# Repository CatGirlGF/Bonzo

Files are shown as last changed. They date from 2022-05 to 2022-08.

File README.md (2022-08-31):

# Bonzo
## Pro Micro based custom pseudo 40% keyboard inspired by [V4N4G0N](https://trashman.wiki/keyboards/v4n4g0n)

Bonzo

## Kicad libraries used:

https://github.com/AcheronProject/AlexandriaLibrary
https://github.com/keebio/Keebio-Parts.pretty
https://github.com/ai03-2725/MX_Alps_Hybrid/tree/master/MX_Only.pretty

## Gerbers

The provided gerbers have been created according to the specifications of JLCpcb. For plate the size is 275.3mm * 113.4mm

## Cases 

### Acryllic case

The case is designed to be cut out of 3mm acryllic and uses a 1.5mm switchplate.

I used 4mm female to female M2 standoffs from this listing: https://www.aliexpress.com/item/1005003106030065.html

https://i.imgur.com/W8KVRhH.png Picture for reference if the listing gets deleted

### 3D printable case WIP

This case has been printed fully and works, but the screwholes are too tight and have to be drilled.

Updated case design with heat insrets and correct size holes at some point.

## Firmware 

I have provided a compiled .hex and a layout json that will let you use the keyboard with VIA.

The full QMK library is also provided incase it is needed.

## BOM

### General parts for wired

| Name | Pieces | Description |
| --- | --- | --- |
| PCB | 1 | Gerbers available at this repository |
| 1,5mm switch plate | 1 | Gerbers available at this repository |
| 2U PCB mount stabilizer | 3 | Also known as screw-in stabilizers |
| MX hotswap sockets | 54 | Kailh or equivalent |
| MX style switch | 54 | |
| 1N4148 diodes | 54 | SOD-123 packaging |
| ProMicro or similar | 1 | |

### For Wireless

| Name | Pieces | Description |
| --- | --- | --- |
| PCB | 1 | Gerbers available at this repository |
| 1,5mm switch plate | 1 | Gerbers available at this repository |
| 2U PCB mount stabilizer | 3 | |
| MX hotswap sockets | 54 | Kailh or equivalent |
| MX style switch | 54 | |
| 1N4148 diodes | 54 | SOD-123 packaging |
| nice!nano v2 | 1 | |
| LiPo battery | 1 | Refer to [nice!nano's documentation](https://nicekeyboards.com/docs/nice-nano/) on battery suggestions |
| Slide switch | 1 | JS202011AQN or similar |

#### For acryllic case

| Name | Pieces | Description |
| --- | --- | --- |
| Acrylic layers | 1 of each | Files available in this repository |
| 4-6mm M2 female - female standoffs | 8 | Hexagon shaped ones won't fit |
| M2 screws | 16 | |

#### For 3DP case

| Name | Pieces | Description |
| --- | --- | --- |
| Top case | 1 | |
| Bottom case  | 1 | |
| M2x15 screws | 4 | Self-tapping screws are recommended |
| M2x10 screws | 4 | Self-tapping screws are recommended |

## Keycaps
You will also need keycaps to fit the layout pictured below 
layout

# Disclaimer
**Everything in this repo has been published with intent to allow others to build this keyboard if they want to and is published under MIT License. The versions I have uploaded have been tested to work. I take no responsibility of designs being incorrect or flawed. Check all the files yourself before you purchase anything. If something is broken or missing please let me know and ill try and see if I can fix the issue.**

Also here is the cat who inspired the name and the silkscreen
The boy

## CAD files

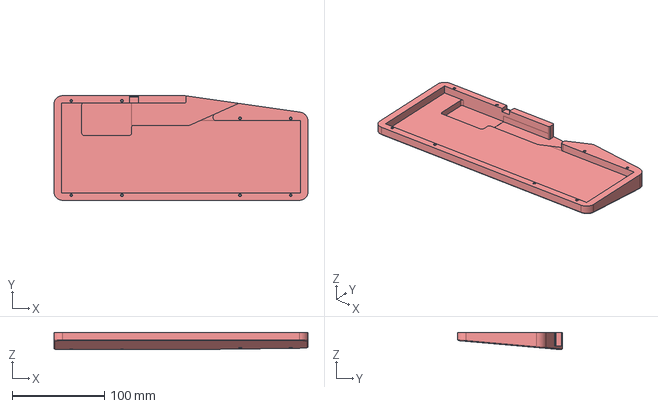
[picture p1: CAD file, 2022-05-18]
3DP Case/Bottom-for-wireless.step
275.3 x 113.4 x 18.9 mm

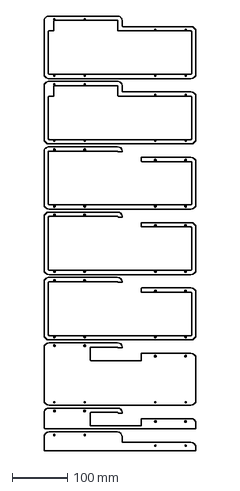
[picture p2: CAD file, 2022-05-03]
Acryllic case/Bonzo_case_fr4_acryllic.dxf
275.3 x 788.2 mm

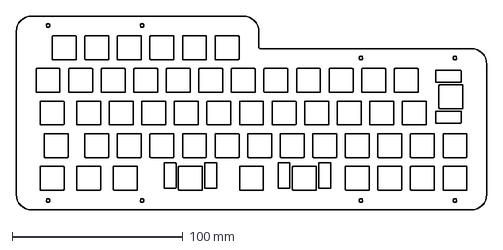
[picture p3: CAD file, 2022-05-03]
Plate/Bonzo_v2_plate_dxf.dxf
275.3 x 113.4 mm

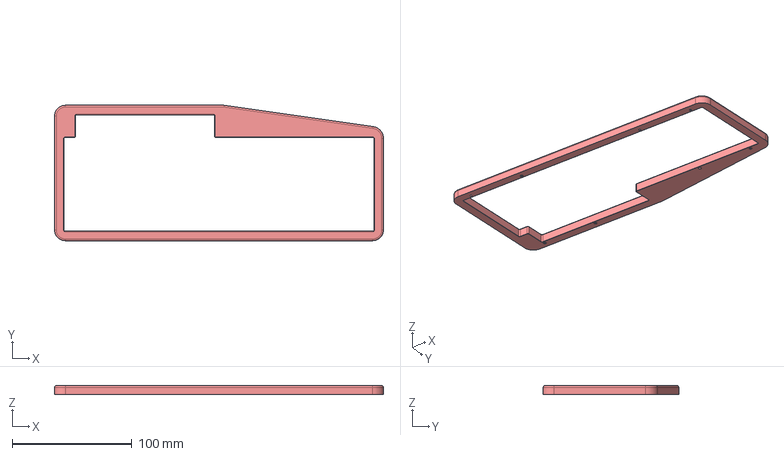
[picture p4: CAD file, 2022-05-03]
3DP Case/Top.step
275.3 x 113.4 x 7.50 mm

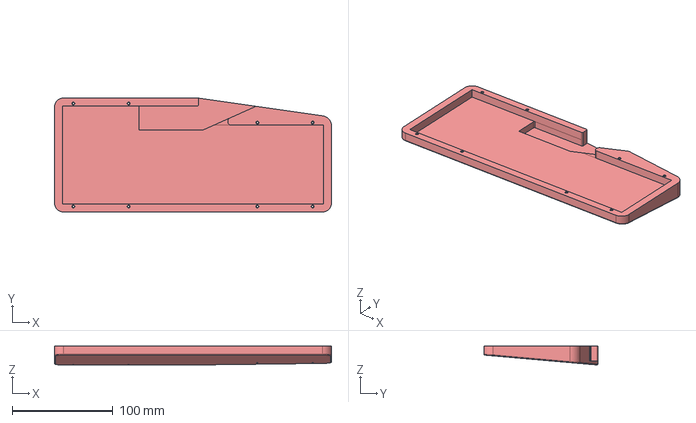
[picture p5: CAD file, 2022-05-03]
3DP Case/Bottom.step
275.3 x 113.4 x 18.9 mm

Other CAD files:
3DP Case/Bottom_fixed_screwholes_PART_NOT_TESTED.stl
3DP Case/Bottom-for-wireless.stl
3DP Case/Bottom.stl
3DP Case/Top.stl

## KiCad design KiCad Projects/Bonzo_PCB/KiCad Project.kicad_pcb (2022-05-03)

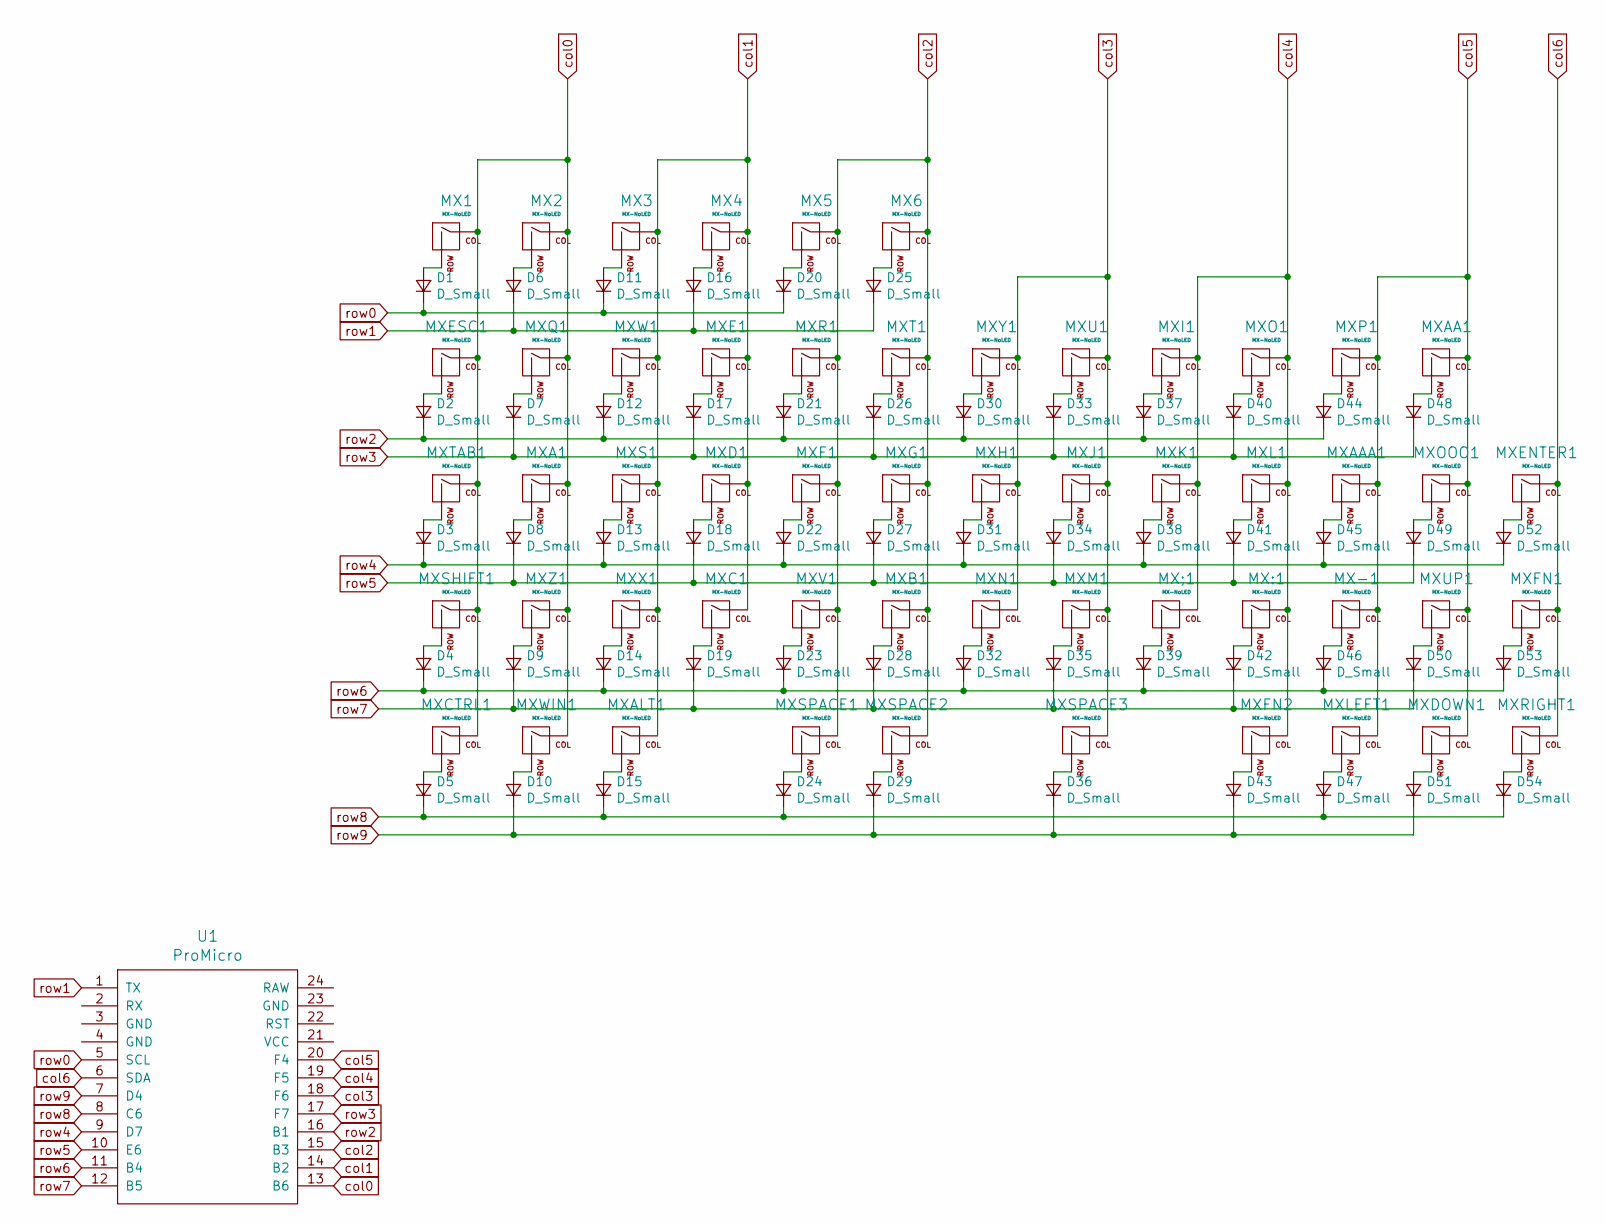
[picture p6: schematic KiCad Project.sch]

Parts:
D1, D2, D3, D4, D5, D6, D7, D8, D9, D10, D11, D12, D13, D14, D15, D16, D17, D18, D19, D20, D21, D22, D23, D24, D25, D26, D27, D28, D29, D30, D31, D32, D33, D34, D35, D36, D37, D38, D39, D40, D41, D42, D43, D44, D45, D46, D47, D48, D49, D50, D51, D52, D53, D54: D_Small; D_SOD123
MX1, MX2, MX3, MX4, MX5, MX6: MX-NoLED; MXOnly-1U-Hotswap
MX-1: MX-NoLED; MXOnly-1U-Hotswap
MX:1: MX-NoLED; MXOnly-1U-Hotswap
MX;1: MX-NoLED; MXOnly-1U-Hotswap
MXA1: MX-NoLED; MXOnly-1U-Hotswap
MXAA1: MX-NoLED; MXOnly-1U-Hotswap
MXAAA1: MX-NoLED; MXOnly-1U-Hotswap
MXALT1: MX-NoLED; MXOnly-1.25U-Hotswap
MXB1: MX-NoLED; MXOnly-1U-Hotswap
MXC1: MX-NoLED; MXOnly-1U-Hotswap
MXCTRL1: MX-NoLED; MXOnly-1.25U-Hotswap
MXD1: MX-NoLED; MXOnly-1U-Hotswap
MXDOWN1: MX-NoLED; MXOnly-1U-Hotswap
MXE1: MX-NoLED; MXOnly-1U-Hotswap
MXENTER1: MX-NoLED; MX_ISOEnter_VerticalH
MXESC1: MX-NoLED; MXOnly-1U-Hotswap
MXF1: MX-NoLED; MXOnly-1U-Hotswap
MXFN1, MXFN2: MX-NoLED; MXOnly-1U-Hotswap
MXG1: MX-NoLED; MXOnly-1U-Hotswap
MXH1: MX-NoLED; MXOnly-1U-Hotswap
MXI1: MX-NoLED; MXOnly-1U-Hotswap
MXJ1: MX-NoLED; MXOnly-1U-Hotswap
MXK1: MX-NoLED; MXOnly-1U-Hotswap
MXL1: MX-NoLED; MXOnly-1U-Hotswap
MXLEFT1: MX-NoLED; MXOnly-1U-Hotswap
MXM1: MX-NoLED; MXOnly-1U-Hotswap
MXN1: MX-NoLED; MXOnly-1U-Hotswap
MXO1: MX-NoLED; MXOnly-1U-Hotswap
MXOOO1: MX-NoLED; MXOnly-1U-Hotswap
MXP1: MX-NoLED; MXOnly-1U-Hotswap
MXQ1: MX-NoLED; MXOnly-1U-Hotswap
MXR1: MX-NoLED; MXOnly-1U-Hotswap
MXRIGHT1: MX-NoLED; MXOnly-1U-Hotswap
MXS1: MX-NoLED; MXOnly-1U-Hotswap
MXSHIFT1: MX-NoLED; MXOnly-1.5U-Hotswap
MXSPACE1: MX-NoLED; MXOnly-2.75U-Hotswap-ReversedStabilizers
MXSPACE2: MX-NoLED; MXOnly-1U-Hotswap
MXSPACE3: MX-NoLED; MXOnly-2.25U-Hotswap-ReversedStabilizers
MXT1: MX-NoLED; MXOnly-1U-Hotswap
MXTAB1: MX-NoLED; MXOnly-1.25U-Hotswap
MXU1: MX-NoLED; MXOnly-1U-Hotswap
MXUP1: MX-NoLED; MXOnly-1U-Hotswap
MXV1: MX-NoLED; MXOnly-1U-Hotswap
MXW1: MX-NoLED; MXOnly-1U-Hotswap
MXWIN1: MX-NoLED; MXOnly-1U-Hotswap
MXX1: MX-NoLED; MXOnly-1U-Hotswap
MXY1: MX-NoLED; MXOnly-1U-Hotswap
MXZ1: MX-NoLED; MXOnly-1U-Hotswap
U1: ProMicro; ArduinoProMicro

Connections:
unnamed: D1.2 (A), MX1.2 (ROW)
unnamed: D2.2 (A), MXESC1.2 (ROW)
unnamed: D3.2 (A), MXTAB1.2 (ROW)
unnamed: D4.2 (A), MXSHIFT1.2 (ROW)
unnamed: D5.2 (A), MXCTRL1.2 (ROW)
unnamed: D6.2 (A), MX2.2 (ROW)
unnamed: D7.2 (A), MXQ1.2 (ROW)
unnamed: D8.2 (A), MXA1.2 (ROW)
unnamed: D9.2 (A), MXZ1.2 (ROW)
unnamed: D10.2 (A), MXWIN1.2 (ROW)
unnamed: D11.2 (A), MX3.2 (ROW)
unnamed: D12.2 (A), MXW1.2 (ROW)
unnamed: D13.2 (A), MXS1.2 (ROW)
unnamed: D14.2 (A), MXX1.2 (ROW)
unnamed: D15.2 (A), MXALT1.2 (ROW)
unnamed: D16.2 (A), MX4.2 (ROW)
unnamed: D17.2 (A), MXE1.2 (ROW)
unnamed: D18.2 (A), MXD1.2 (ROW)
unnamed: D19.2 (A), MXC1.2 (ROW)
unnamed: D20.2 (A), MX5.2 (ROW)
unnamed: D21.2 (A), MXR1.2 (ROW)
unnamed: D22.2 (A), MXF1.2 (ROW)
unnamed: D23.2 (A), MXV1.2 (ROW)
unnamed: D24.2 (A), MXSPACE1.2 (ROW)
unnamed: D25.2 (A), MX6.2 (ROW)
unnamed: D26.2 (A), MXT1.2 (ROW)
unnamed: D27.2 (A), MXG1.2 (ROW)
unnamed: D28.2 (A), MXB1.2 (ROW)
unnamed: D29.2 (A), MXSPACE2.2 (ROW)
unnamed: D30.2 (A), MXY1.2 (ROW)
unnamed: D31.2 (A), MXH1.2 (ROW)
unnamed: D32.2 (A), MXN1.2 (ROW)
unnamed: D33.2 (A), MXU1.2 (ROW)
unnamed: D34.2 (A), MXJ1.2 (ROW)
unnamed: D35.2 (A), MXM1.2 (ROW)
unnamed: D36.2 (A), MXSPACE3.2 (ROW)
unnamed: D37.2 (A), MXI1.2 (ROW)
unnamed: D38.2 (A), MXK1.2 (ROW)
unnamed: D39.2 (A), MX;1.2 (ROW)
unnamed: D40.2 (A), MXO1.2 (ROW)
unnamed: D41.2 (A), MXL1.2 (ROW)
unnamed: D42.2 (A), MX:1.2 (ROW)
unnamed: D43.2 (A), MXFN2.2 (ROW)
unnamed: D44.2 (A), MXP1.2 (ROW)
unnamed: D45.2 (A), MXAAA1.2 (ROW)
unnamed: D46.2 (A), MX-1.2 (ROW)
unnamed: D47.2 (A), MXLEFT1.2 (ROW)
unnamed: D48.2 (A), MXAA1.2 (ROW)
unnamed: D49.2 (A), MXOOO1.2 (ROW)
unnamed: D50.2 (A), MXUP1.2 (ROW)
unnamed: D51.2 (A), MXDOWN1.2 (ROW)
unnamed: D52.2 (A), MXENTER1.2 (ROW)
unnamed: D53.2 (A), MXFN1.2 (ROW)
unnamed: D54.2 (A), MXRIGHT1.2 (ROW)
col0: MX1.1 (COL), MX2.1 (COL), MXA1.1 (COL), MXCTRL1.1 (COL), MXESC1.1 (COL), MXQ1.1 (COL), MXSHIFT1.1 (COL), MXTAB1.1 (COL), MXWIN1.1 (COL), MXZ1.1 (COL), U1.13 (B6)
col1: MX3.1 (COL), MX4.1 (COL), MXALT1.1 (COL), MXC1.1 (COL), MXD1.1 (COL), MXE1.1 (COL), MXS1.1 (COL), MXW1.1 (COL), MXX1.1 (COL), U1.14 (B2)
col2: MX5.1 (COL), MX6.1 (COL), MXB1.1 (COL), MXF1.1 (COL), MXG1.1 (COL), MXR1.1 (COL), MXSPACE1.1 (COL), MXSPACE2.1 (COL), MXT1.1 (COL), MXV1.1 (COL), U1.15 (B3)
col3: MXH1.1 (COL), MXJ1.1 (COL), MXM1.1 (COL), MXN1.1 (COL), MXSPACE3.1 (COL), MXU1.1 (COL), MXY1.1 (COL), U1.18 (F6)
col4: MX:1.1 (COL), MX;1.1 (COL), MXFN2.1 (COL), MXI1.1 (COL), MXK1.1 (COL), MXL1.1 (COL), MXO1.1 (COL), U1.19 (F5)
col5: MX-1.1 (COL), MXAA1.1 (COL), MXAAA1.1 (COL), MXDOWN1.1 (COL), MXLEFT1.1 (COL), MXOOO1.1 (COL), MXP1.1 (COL), MXUP1.1 (COL), U1.20 (F4)
col6: MXENTER1.1 (COL), MXFN1.1 (COL), MXRIGHT1.1 (COL), U1.6 (SDA)
row0: D1.1 (K), D11.1 (K), D20.1 (K), U1.5 (SCL)
row1: D6.1 (K), D16.1 (K), D25.1 (K), U1.1 (TX)
row2: D2.1 (K), D12.1 (K), D21.1 (K), D30.1 (K), D37.1 (K), D44.1 (K), U1.16 (B1)
row3: D7.1 (K), D17.1 (K), D26.1 (K), D33.1 (K), D40.1 (K), D48.1 (K), U1.17 (F7)
row4: D3.1 (K), D13.1 (K), D22.1 (K), D31.1 (K), D38.1 (K), D45.1 (K), D52.1 (K), U1.9 (D7)
row5: D8.1 (K), D18.1 (K), D27.1 (K), D34.1 (K), D41.1 (K), D49.1 (K), U1.10 (E6)
row6: D4.1 (K), D14.1 (K), D23.1 (K), D32.1 (K), D39.1 (K), D46.1 (K), D53.1 (K), U1.11 (B4)
row7: D9.1 (K), D19.1 (K), D28.1 (K), D35.1 (K), D42.1 (K), D50.1 (K), U1.12 (B5)
row8: D5.1 (K), D15.1 (K), D24.1 (K), D47.1 (K), D54.1 (K), U1.8 (C6)
row9: D10.1 (K), D29.1 (K), D36.1 (K), D43.1 (K), D51.1 (K), U1.7 (D4)

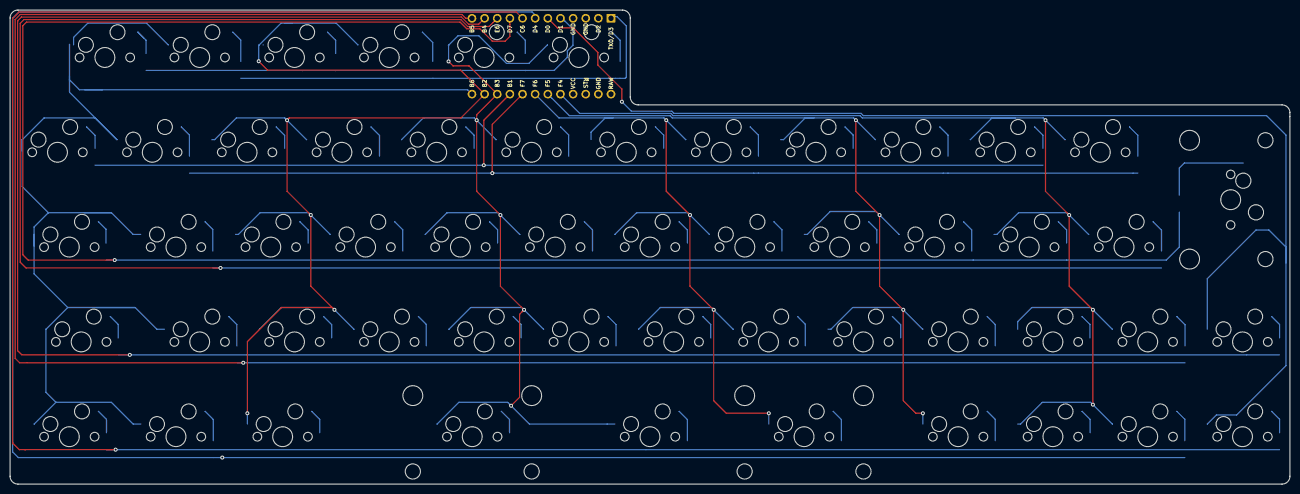
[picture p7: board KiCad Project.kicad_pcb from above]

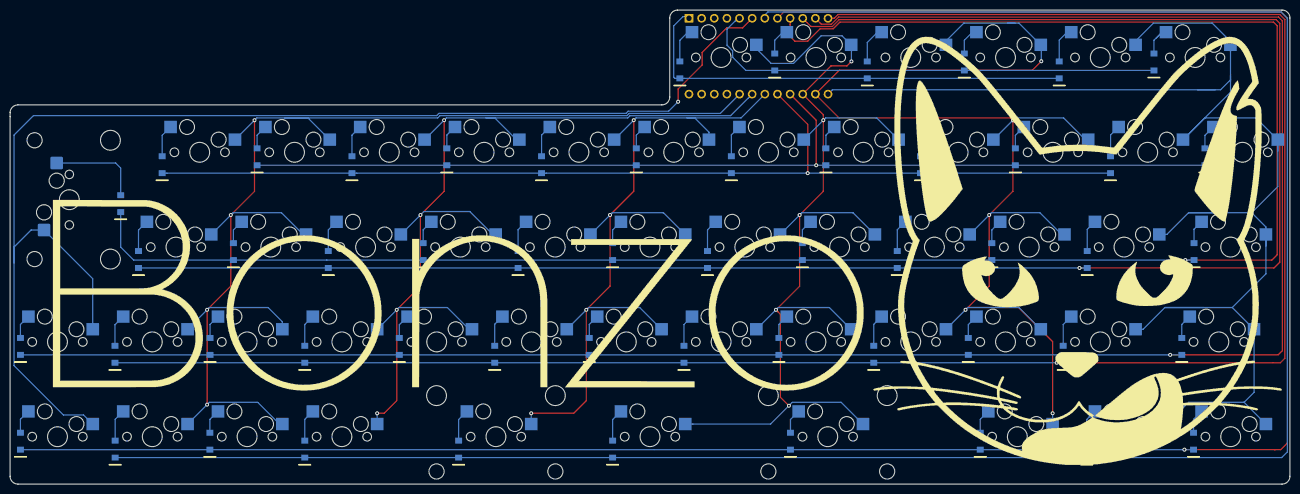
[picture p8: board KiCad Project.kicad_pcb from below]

Board: 2 copper layers, 257.2 x 95.2 mm, 109 parts (55 on the bottom side), 71 nets.

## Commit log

2022-05-14 Added a case with battery compartment
    [Bottom-with-battery.step, Bottom_with_battery.stl]
2022-05-18 Add ZMK board config + 3DP case files for wireless version.
    [Bottom-for-wireless.step, Bottom-for-wireless.stl, Bottom-with-battery.step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]
